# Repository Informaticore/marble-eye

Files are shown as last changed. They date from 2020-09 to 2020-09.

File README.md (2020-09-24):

# Marble Eye
Marble Eye is an IR pass through Sensor for a project I am working on. It can detect objects which are passing by at a distance with up to 2cm.

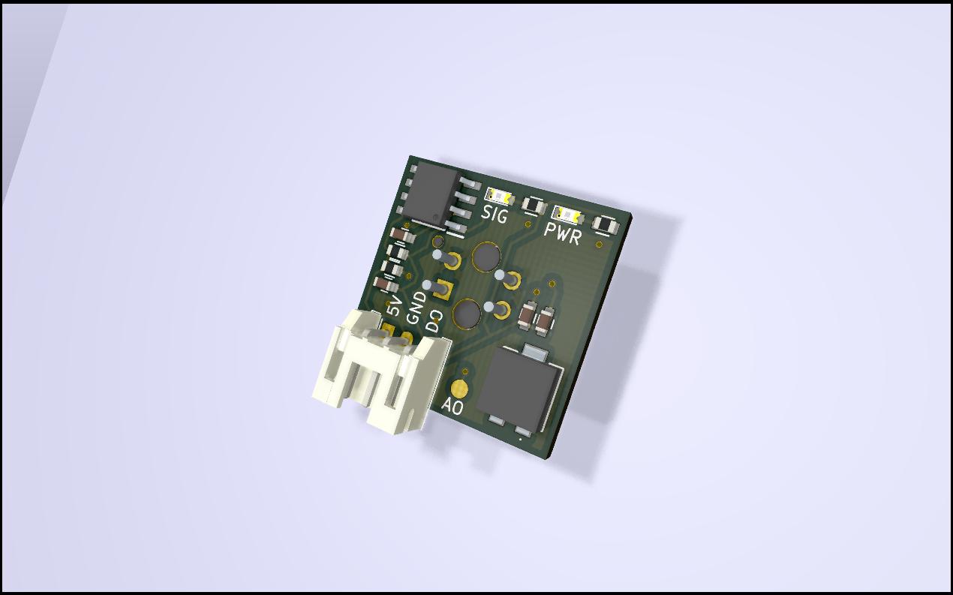
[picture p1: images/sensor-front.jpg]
Marble Eye Front

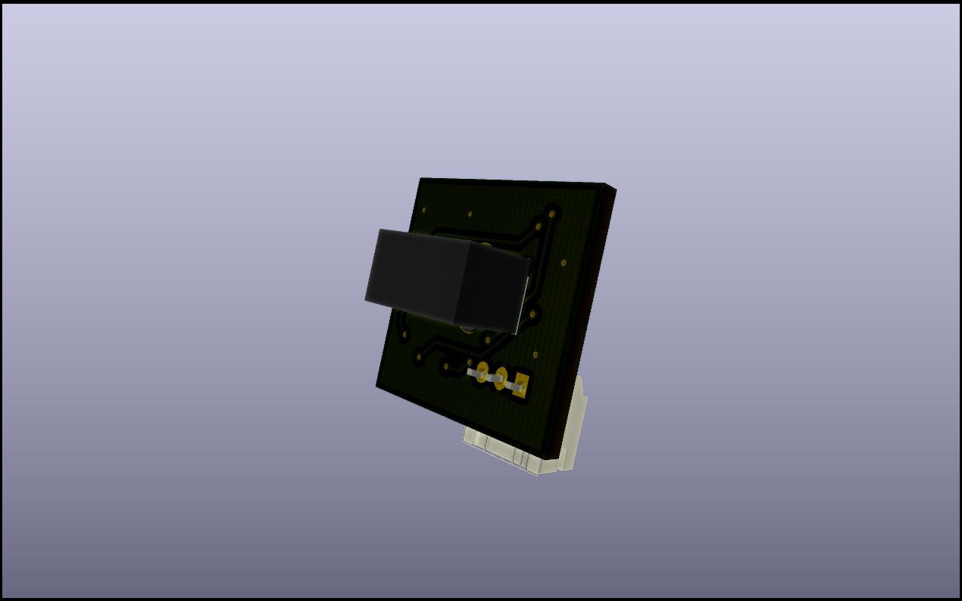
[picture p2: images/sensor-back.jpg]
Marble Eye Back


# Marble Eye Hub
The Marble Eye Hub is a GPIO-Expander with 16 Ports to connect up to 16 Marble Eyes to it. Based on interrupts the Hub can detect pass through on all 16 channels.

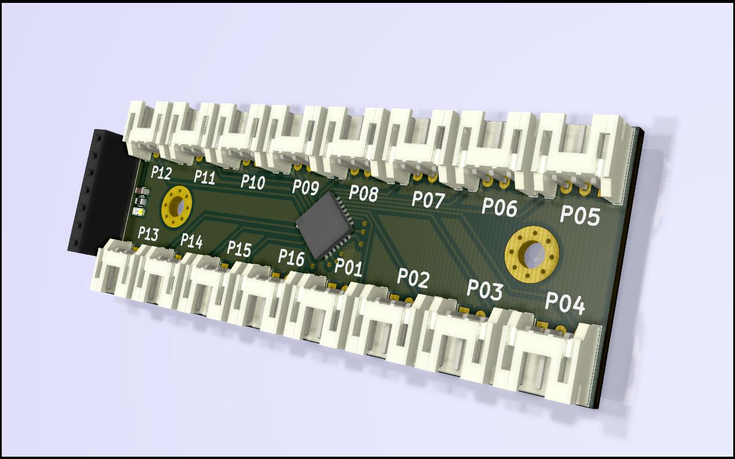
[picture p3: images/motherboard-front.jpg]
Marble Eye Hub


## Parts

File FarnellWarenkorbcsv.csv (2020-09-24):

Nr. | Best.-Nr. | RoHS-konform? | Ihre Bestellnummer | Hinweise | Menge | Hersteller-Teilenr. | Herstellername | Hersteller / Beschreibung | Verfügbarkeit | Stückpreis | Positionspreis | Rabattpreis
1 | 2059601 | RoHS: Y-EX / PHTHALATE: YES |  |  | 10.0 | ERJ3GEYJ102V | PANASONIC | PANASONIC Chipwiderstand, Oberflächenmontage, Dickschicht, 0603 [Metrisch 1608], 1 kohm, Baureihe ERJ3G, 75 V | 151696 | 0.0579 | 0.58
2 | 2059583 | RoHS: Y-EX / PHTHALATE: YES |  |  | 10.0 | ERJ3GEYJ221V | PANASONIC | PANASONIC Chipwiderstand, Oberflächenmontage, Dickschicht, 0603 [Metrisch 1608], 220 ohm, Baureihe ERJ3G | 11262 | 0.0565 | 0.57
3 | 2059627 | RoHS: Y-EX / PHTHALATE: YES |  |  | 20.0 | ERJ3GEYJ103V | PANASONIC | PANASONIC Chipwiderstand, Oberflächenmontage, Dickschicht, 0603 [Metrisch 1608], 10 kohm, Baureihe ERJ3G | 343293 | 0.0551 | 1.10
4 | 3616198 | RoHS: YES / PHTHALATE: YES |  |  | 100.0 | PHR-3 | JST (JAPAN SOLDERLESS TERMINALS) | JST (JAPAN SOLDERLESS TERMINALS) Steckverbindergehäuse, Baureihe PH, Buchse, 3 -polig, 2 mm, Crimpkontakte der Baureihen BPH und SPH | 113015 | 0.0389 | 3.89
5 | 9491910 | RoHS: YES / PHTHALATE: YES |  |  | 100.0 | S3B-PH-K-S (LF)(SN) | JST (JAPAN SOLDERLESS TERMINALS) | JST (JAPAN SOLDERLESS TERMINALS) Stiftleiste, abgewinkelt, Wire-to-Board, 2 mm, 1 Reihe(n), 3 Kontakt(e) | 3933 | 0.0940 | 9.40
6 | 1671245 | RoHS: YES / PHTHALATE: YES |  |  | 300.0 | SPH-002T-P0.5S | JST (JAPAN SOLDERLESS TERMINALS) | JST (JAPAN SOLDERLESS TERMINALS) Kontakt, Baureihe PH, Buchsenkontakt, Crimpanschluss, 24 AWG, Verzinnte Kontakte | 155877 | 0.0244 | 7.32
7 | 2322071 | RoHS: YES / PHTHALATE: YES |  |  | 50.0 | 150060RS75000 | WURTH ELEKTRONIK | WURTH ELEKTRONIK LED, Rot, Oberflächenmontage, 603, 30 mA, 2 V, 625 nm | 7565 | 0.1430 | 7.15
8 | 2303104 | RoHS: Y-EX / PHTHALATE: YES |  |  | 100.0 | ERJ3EKF3300V | PANASONIC | PANASONIC Chipwiderstand, Oberflächenmontage, Dickschicht, 0603 [Metrisch 1608], 330 ohm, Baureihe ERJ3E | 15098 | 0.0365 | 3.65
9 | 2210887 | RoHS: YES / PHTHALATE: YES |  |  | 100.0 | CGA3E2X8R1E104K080AA | TDK | TDK Keramikvielschichtkondensator, SMD, 0.1 µF, 25 V, 0603 [Metrisch 1608], ± 10%, X8R, Baureihe CGA | 78194 | 0.0715 | 7.15
10 | 1470066 | RoHS: YES / PHTHALATE: YES |  |  | 10.0 | TCRT5000 | VISHAY | VISHAY Reflexlichtschranke, Fototransistor, Durchsteckmontage, 15mm, 60mA, 5Vr, 1.25Vf | 1556 | 1.0700 | 10.70
11 | 1141474 | RoHS: YES / PHTHALATE: YES |  |  | 10.0 | TS53YL103MR10 | VISHAY | VISHAY Trimmpotentiometer, Eingängig, Cermet, Einstellung oben, 10 kohm, Oberflächenmontage | 5750 | 1.0600 | 10.60
12 | 2857786 | RoHS: YES / PHTHALATE: YES |  |  | 5.0 | MCP23017T-E/ML | MICROCHIP | MICROCHIP I/O-Erweiterung, 16bit, 1.7 MHz, I2C, 1.8 V, 5.5 V, QFN | 3178 | 1.3400 | 6.70
 |  |  |  |  |  |  | Zwischensumme | 68.81
 |  |  |  |  |  |  | Warengesamtsumme | 68.81
 |  |  |  |  |  |  | Lieferung | 0.00
 |  |  |  |  |  |  | USt. | 13.07
 |  |  |  |  |  |  | Gesamt | 81.88

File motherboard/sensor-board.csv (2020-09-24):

Source: | C:\Users\Informatic0re\Documents\workspace\ir-detector\motherboard\sensor-board.sch
Date: | 07/06/2020 14:44:52
Tool: | Eeschema (5.1.2)-1
Generator: | E:\KiCad\bin\scripting\plugins/bom_csv_grouped_by_value.py
Component Count: | 23
Individual Components:
Item | Qty | Reference(s) | Value | LibPart | Footprint | Datasheet | Link | ManufacturerId
 |  | C1 | 100nF | Device:C | Capacitors_SMD:C_0603 | ~ | https://www.mouser.de/ProductDetail/81-GCJ188R71C104MA1D | GCJ188R71C104MA01D
 |  | D1 | LED | Device:LED | LEDs:LED_0603 | ~ | https://www.mouser.de/ProductDetail/710-150060RS75000 | 150060RS75000
 |  | H1 | MountingHole | Mechanical:MountingHole | Mounting_Holes:MountingHole_3mm_Pad_Via | ~
 |  | H2 | MountingHole | Mechanical:MountingHole | Mounting_Holes:MountingHole_3mm_Pad_Via | ~
 |  | J1 | S3B-PH | Connector:Conn_01x03_Male | Connectors_JST:JST_PH_S3B-PH-K_03x2.00mm_Angled | ~ | https://de.farnell.com/jst-japan-solderless-terminals/s3b-ph-k-s-lf-sn/stecker-seitlicher-eing-3kont/dp/9491910 | S3B-PH-K-S (LF)(SN)
 |  | J2 | S3B-PH | Connector:Conn_01x03_Male | Connectors_JST:JST_PH_S3B-PH-K_03x2.00mm_Angled | ~ | https://de.farnell.com/jst-japan-solderless-terminals/s3b-ph-k-s-lf-sn/stecker-seitlicher-eing-3kont/dp/9491910 | S3B-PH-K-S (LF)(SN)
 |  | J3 | S3B-PH | Connector:Conn_01x03_Male | Connectors_JST:JST_PH_S3B-PH-K_03x2.00mm_Angled | ~ | https://de.farnell.com/jst-japan-solderless-terminals/s3b-ph-k-s-lf-sn/stecker-seitlicher-eing-3kont/dp/9491910 | S3B-PH-K-S (LF)(SN)
 |  | J4 | S3B-PH | Connector:Conn_01x03_Male | Connectors_JST:JST_PH_S3B-PH-K_03x2.00mm_Angled | ~ | https://de.farnell.com/jst-japan-solderless-terminals/s3b-ph-k-s-lf-sn/stecker-seitlicher-eing-3kont/dp/9491910 | S3B-PH-K-S (LF)(SN)
 |  | J5 | S3B-PH | Connector:Conn_01x03_Male | Connectors_JST:JST_PH_S3B-PH-K_03x2.00mm_Angled | ~ | https://de.farnell.com/jst-japan-solderless-terminals/s3b-ph-k-s-lf-sn/stecker-seitlicher-eing-3kont/dp/9491910 | S3B-PH-K-S (LF)(SN)
 |  | J6 | S3B-PH | Connector:Conn_01x03_Male | Connectors_JST:JST_PH_S3B-PH-K_03x2.00mm_Angled | ~ | https://de.farnell.com/jst-japan-solderless-terminals/s3b-ph-k-s-lf-sn/stecker-seitlicher-eing-3kont/dp/9491910 | S3B-PH-K-S (LF)(SN)
 |  | J7 | S3B-PH | Connector:Conn_01x03_Male | Connectors_JST:JST_PH_S3B-PH-K_03x2.00mm_Angled | ~ | https://de.farnell.com/jst-japan-solderless-terminals/s3b-ph-k-s-lf-sn/stecker-seitlicher-eing-3kont/dp/9491910 | S3B-PH-K-S (LF)(SN)
 |  | J8 | S3B-PH | Connector:Conn_01x03_Male | Connectors_JST:JST_PH_S3B-PH-K_03x2.00mm_Angled | ~ | https://de.farnell.com/jst-japan-solderless-terminals/s3b-ph-k-s-lf-sn/stecker-seitlicher-eing-3kont/dp/9491910 | S3B-PH-K-S (LF)(SN)
 |  | J9 | S3B-PH | Connector:Conn_01x03_Male | Connectors_JST:JST_PH_S3B-PH-K_03x2.00mm_Angled | ~ | https://de.farnell.com/jst-japan-solderless-terminals/s3b-ph-k-s-lf-sn/stecker-seitlicher-eing-3kont/dp/9491910 | S3B-PH-K-S (LF)(SN)
 |  | J10 | S3B-PH | Connector:Conn_01x03_Male | Connectors_JST:JST_PH_S3B-PH-K_03x2.00mm_Angled | ~ | https://de.farnell.com/jst-japan-solderless-terminals/s3b-ph-k-s-lf-sn/stecker-seitlicher-eing-3kont/dp/9491910 | S3B-PH-K-S (LF)(SN)
 |  | J11 | S3B-PH | Connector:Conn_01x03_Male | Connectors_JST:JST_PH_S3B-PH-K_03x2.00mm_Angled | ~ | https://de.farnell.com/jst-japan-solderless-terminals/s3b-ph-k-s-lf-sn/stecker-seitlicher-eing-3kont/dp/9491910 | S3B-PH-K-S (LF)(SN)
 |  | J12 | S3B-PH | Connector:Conn_01x03_Male | Connectors_JST:JST_PH_S3B-PH-K_03x2.00mm_Angled | ~ | https://de.farnell.com/jst-japan-solderless-terminals/s3b-ph-k-s-lf-sn/stecker-seitlicher-eing-3kont/dp/9491910 | S3B-PH-K-S (LF)(SN)
 |  | J13 | S3B-PH | Connector:Conn_01x03_Male | Connectors_JST:JST_PH_S3B-PH-K_03x2.00mm_Angled | ~ | https://de.farnell.com/jst-japan-solderless-terminals/s3b-ph-k-s-lf-sn/stecker-seitlicher-eing-3kont/dp/9491910 | S3B-PH-K-S (LF)(SN)
 |  | J14 | S3B-PH | Connector:Conn_01x03_Male | Connectors_JST:JST_PH_S3B-PH-K_03x2.00mm_Angled | ~ | https://de.farnell.com/jst-japan-solderless-terminals/s3b-ph-k-s-lf-sn/stecker-seitlicher-eing-3kont/dp/9491910 | S3B-PH-K-S (LF)(SN)
 |  | J15 | S3B-PH | Connector:Conn_01x03_Male | Connectors_JST:JST_PH_S3B-PH-K_03x2.00mm_Angled | ~ | https://de.farnell.com/jst-japan-solderless-terminals/s3b-ph-k-s-lf-sn/stecker-seitlicher-eing-3kont/dp/9491910 | S3B-PH-K-S (LF)(SN)
 |  | J16 | S3B-PH | Connector:Conn_01x03_Male | Connectors_JST:JST_PH_S3B-PH-K_03x2.00mm_Angled | ~ | https://de.farnell.com/jst-japan-solderless-terminals/s3b-ph-k-s-lf-sn/stecker-seitlicher-eing-3kont/dp/9491910 | S3B-PH-K-S (LF)(SN)
 |  | J17 | DNP | Connector:Conn_01x06_Male | Connector_PinSocket_2.54mm:PinSocket_1x06_P2.54mm_Vertical | ~
 |  | R1 | 300 | Device:R | Resistors_SMD:R_0603 | ~ | https://www.mouser.de/ProductDetail/667-ERJ-3RBD3000V | ERJ-3RBD3000V
 |  | U1 | MCP23017_ML | Interface_Expansion:MCP23017_ML | motherboard:QFN65P600X600X100-29N-D | http://ww1.microchip.com/downloads/en/DeviceDoc/20001952C.pdf |  | 74438366015
Collated Components:
Item | Qty | Reference(s) | Value | LibPart | Footprint | Datasheet | Link | ManufacturerId
1 | 1 | C1 | 100nF | Device:C | Capacitors_SMD:C_0603 | ~ | https://www.mouser.de/ProductDetail/81-GCJ188R71C104MA1D | GCJ188R71C104MA01D
2 | 1 | D1 | LED | Device:LED | LEDs:LED_0603 | ~ | https://www.mouser.de/ProductDetail/710-150060RS75000 | 150060RS75000
3 | 2 | H1, H2 | MountingHole | Mechanical:MountingHole | Mounting_Holes:MountingHole_3mm_Pad_Via | ~
4 | 16 | J1, J2, J3, J4, J5, J6, J7, J8, J9, J10, J11, J12, J13, J14, J15, J16 | S3B-PH | Connector:Conn_01x03_Male | Connectors_JST:JST_PH_S3B-PH-K_03x2.00mm_Angled | ~ | https://de.farnell.com/jst-japan-solderless-terminals/s3b-ph-k-s-lf-sn/stecker-seitlicher-eing-3kont/dp/9491910 | S3B-PH-K-S (LF)(SN)
5 | 1 | J17 | DNP | Connector:Conn_01x06_Male | Connector_PinSocket_2.54mm:PinSocket_1x06_P2.54mm_Vertical | ~
6 | 1 | R1 | 300 | Device:R | Resistors_SMD:R_0603 | ~ | https://www.mouser.de/ProductDetail/667-ERJ-3RBD3000V | ERJ-3RBD3000V
7 | 1 | U1 | MCP23017_ML | Interface_Expansion:MCP23017_ML | motherboard:QFN65P600X600X100-29N-D | http://ww1.microchip.com/downloads/en/DeviceDoc/20001952C.pdf |  | 74438366015

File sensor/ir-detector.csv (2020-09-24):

Source: | C:\Users\Informatic0re\Documents\workspace\ir-detector\sensor\ir-detector.sch
Date: | 07/06/2020 14:44:30
Tool: | Eeschema (5.1.2)-1
Generator: | E:\KiCad\bin\scripting\plugins/bom_csv_grouped_by_value.py
Component Count: | 15
Individual Components:
Item | Qty | Reference(s) | Value | LibPart | Footprint | Datasheet | Allied Price/Stock | Allied_Number | Arrow Part Number | Arrow Price/Stock | Description | Height | Manufacturer_Name | Manufacturer_Part_Number | Mouser Part Number | Mouser Price/Stock | RS Part Number | RS Price/Stock
 |  | C1 | 104 | Device:C | Capacitors_SMD:C_0603 | ~
 |  | C2 | 104 | Device:C | Capacitors_SMD:C_0603 | ~
 |  | D1 | LED | Device:LED | LEDs:LED_0603 | ~
 |  | D2 | LED | Device:LED | LEDs:LED_0603 | ~
 |  | H1 | M2 | Mechanical:MountingHole | Mounting_Holes:MountingHole_2.2mm_M2_Pad_Via | ~
 |  | IC1 | LM393DR | LM393DR:LM393DR | ir-detector:SOIC127P600X175-8N | http://docs-emea.rs-online.com/webdocs/14b2/0900766b814b2f20.pdf |  |  | LM393DR | https://www.arrow.com/en/products/lm393dr/texas-instruments | LM393DR, Dual Comparator Open Collector 1.3us 12 V, 15 V, 18 V, 24 V, 28 V, 3 V, 5 V, 9 V 8-Pin SOIC | 1.75 | Texas Instruments | LM393DR | 595-LM393DR | https://www.mouser.co.uk/ProductDetail/Texas-Instruments/LM393DR?qs=8k%2FZSzWMuCP%2FrtMSX0i7pQ%3D%3D
 |  | J1 | Conn_01x03_Male | Connector:Conn_01x03_Male | Connectors_JST:JST_PH_S3B-PH-K_03x2.00mm_Angled | ~
 |  | Q1 | TCRT5000 | TCRT5000:TCRT5000 | ir-detector:TCRT5000 | http://www.vishay.com/docs/83760/tcrt5000.pdf | http://www.alliedelec.com/vishay-dale-tcrt5000/R1084611/ | R1084611 |  |  | VISHAY - TCRT5000. - SENSOR, OPTICAL, TRANSISTOR O/P | 6.8 | Vishay | TCRT5000 | 782-TCRT5000 | https://www.mouser.co.uk/ProductDetail/Vishay-Semiconductors/TCRT5000?qs=glpcD2KT6uaaYldHGIIt5g%3D%3D | 7085017P | http://uk.rs-online.com/web/p/products/7085017P
 |  | R1 | 220 | Device:R | Resistors_SMD:R_0603 | ~
 |  | R2 | 10k | Device:R | Resistors_SMD:R_0603 | ~
 |  | R3 | 1k | Device:R | Resistors_SMD:R_0603 | ~
 |  | R4 | 10k | Device:R | Resistors_SMD:R_0603 | ~
 |  | R5 | 330 | Device:R | Resistors_SMD:R_0603 | ~
 |  | R6 | 330 | Device:R | Resistors_SMD:R_0603 | ~
 |  | VR1 | TS53YL_10K_20%TR | TS53YL_10K:TS53YL_10K_20%TR | ir-detector:TS53YL204MR10 | https://www.vishay.com/doc?51008 |  |  | TS53YL 10K 20%TR |  | Trimmer Resistors - SMD TS53YL103MR10 | 2 | Vishay | TS53YL 10K 20%TR | 75-TS53YL10K20%TR | https://www.mouser.co.uk/ProductDetail/Vishay-Sprague/TS53YL-10K-20TR?qs=fbr3QJcAB6rQumgcAWaZQw%3D%3D
Collated Components:
Item | Qty | Reference(s) | Value | LibPart | Footprint | Datasheet | Allied Price/Stock | Allied_Number | Arrow Part Number | Arrow Price/Stock | Description | Height | Manufacturer_Name | Manufacturer_Part_Number | Mouser Part Number | Mouser Price/Stock | RS Part Number | RS Price/Stock
1 | 2 | C1, C2 | 104 | Device:C | Capacitors_SMD:C_0603 | ~
2 | 2 | D1, D2 | LED | Device:LED | LEDs:LED_0603 | ~
3 | 1 | H1 | M2 | Mechanical:MountingHole | Mounting_Holes:MountingHole_2.2mm_M2_Pad_Via | ~
4 | 1 | IC1 | LM393DR | LM393DR:LM393DR | ir-detector:SOIC127P600X175-8N | http://docs-emea.rs-online.com/webdocs/14b2/0900766b814b2f20.pdf |  |  | LM393DR | https://www.arrow.com/en/products/lm393dr/texas-instruments | LM393DR, Dual Comparator Open Collector 1.3us 12 V, 15 V, 18 V, 24 V, 28 V, 3 V, 5 V, 9 V 8-Pin SOIC | 1.75 | Texas Instruments | LM393DR | 595-LM393DR | https://www.mouser.co.uk/ProductDetail/Texas-Instruments/LM393DR?qs=8k%2FZSzWMuCP%2FrtMSX0i7pQ%3D%3D
5 | 1 | J1 | Conn_01x03_Male | Connector:Conn_01x03_Male | Connectors_JST:JST_PH_S3B-PH-K_03x2.00mm_Angled | ~
6 | 1 | Q1 | TCRT5000 | TCRT5000:TCRT5000 | ir-detector:TCRT5000 | http://www.vishay.com/docs/83760/tcrt5000.pdf | http://www.alliedelec.com/vishay-dale-tcrt5000/R1084611/ | R1084611 |  |  | VISHAY - TCRT5000. - SENSOR, OPTICAL, TRANSISTOR O/P | 6.8 | Vishay | TCRT5000 | 782-TCRT5000 | https://www.mouser.co.uk/ProductDetail/Vishay-Semiconductors/TCRT5000?qs=glpcD2KT6uaaYldHGIIt5g%3D%3D | 7085017P | http://uk.rs-online.com/web/p/products/7085017P
7 | 1 | R1 | 220 | Device:R | Resistors_SMD:R_0603 | ~
8 | 2 | R2, R4 | 10k | Device:R | Resistors_SMD:R_0603 | ~
9 | 1 | R3 | 1k | Device:R | Resistors_SMD:R_0603 | ~
10 | 2 | R5, R6 | 330 | Device:R | Resistors_SMD:R_0603 | ~
11 | 1 | VR1 | TS53YL_10K_20%TR | TS53YL_10K:TS53YL_10K_20%TR | ir-detector:TS53YL204MR10 | https://www.vishay.com/doc?51008 |  |  | TS53YL 10K 20%TR |  | Trimmer Resistors - SMD TS53YL103MR10 | 2 | Vishay | TS53YL 10K 20%TR | 75-TS53YL10K20%TR | https://www.mouser.co.uk/ProductDetail/Vishay-Sprague/TS53YL-10K-20TR?qs=fbr3QJcAB6rQumgcAWaZQw%3D%3D

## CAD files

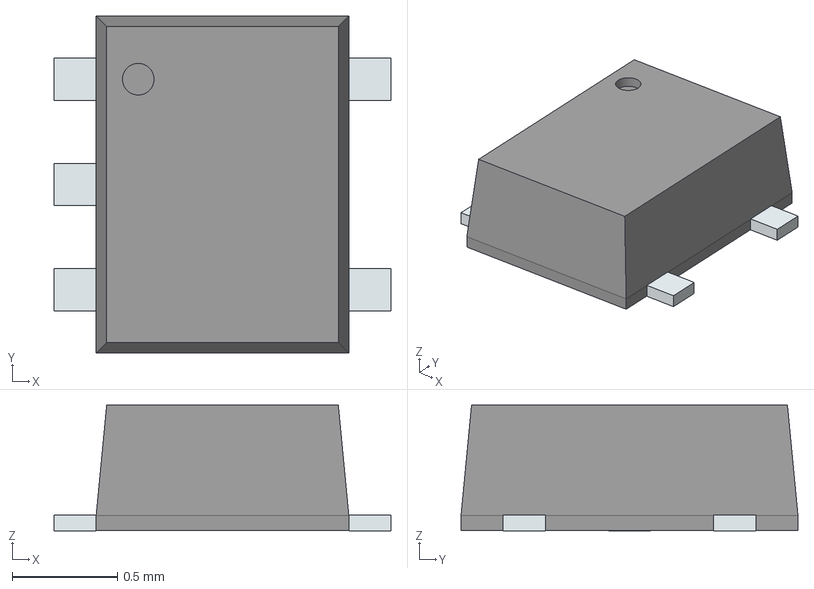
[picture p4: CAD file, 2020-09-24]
motherboard/components/SN74LVC1G32DRLR/3D/SN74LVC1G32DRLR.stp
1.60 x 1.60 x 0.598 mm
PinsArrayL
PinsArrayR

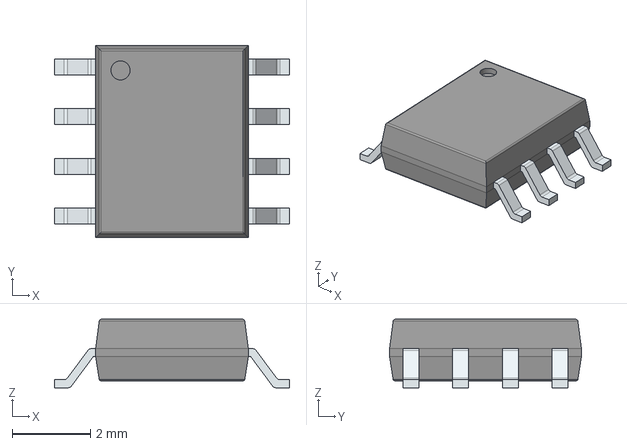
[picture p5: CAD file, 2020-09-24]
sensor/components/LM393DR/3D/LM393DR.stp
6.00 x 4.90 x 1.75 mm
PinsArrayLR

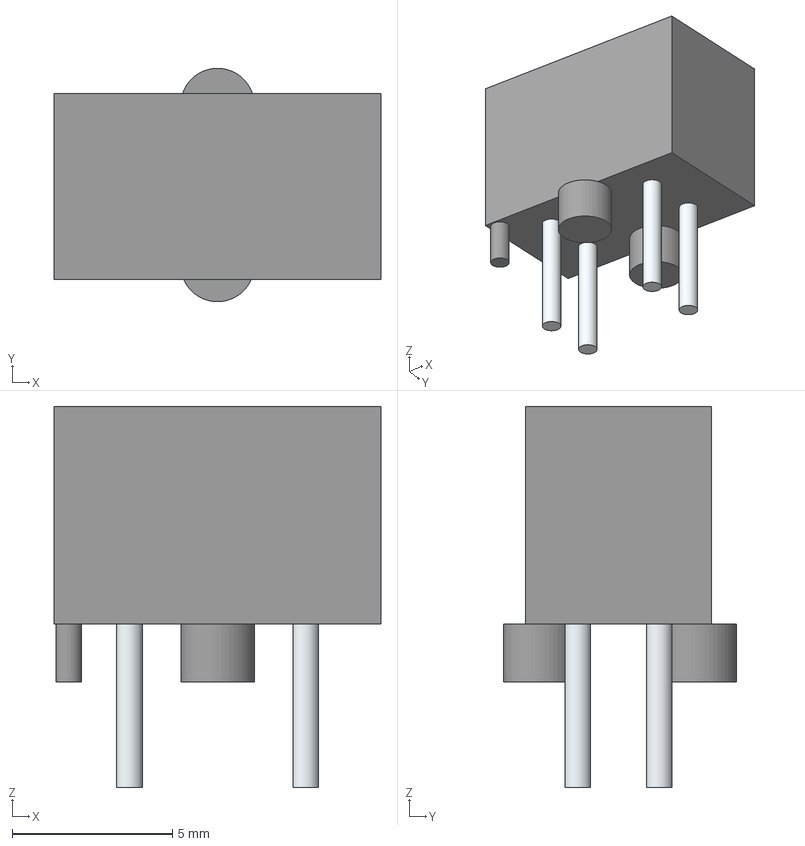
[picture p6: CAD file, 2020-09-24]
sensor/components/TCRT5000/3D/TCRT5000.stp
10.2 x 7.29 x 11.9 mm
Lugs x 7
Leads x 7

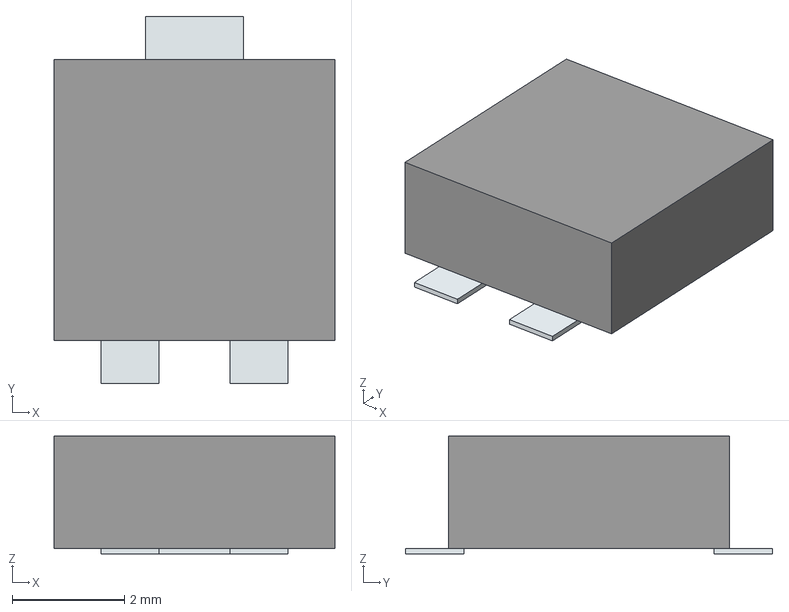
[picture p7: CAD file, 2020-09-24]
sensor/components/TS53YL_10K/3D/TS53YL_10K.stp
5.00 x 6.54 x 2.10 mm
Pins

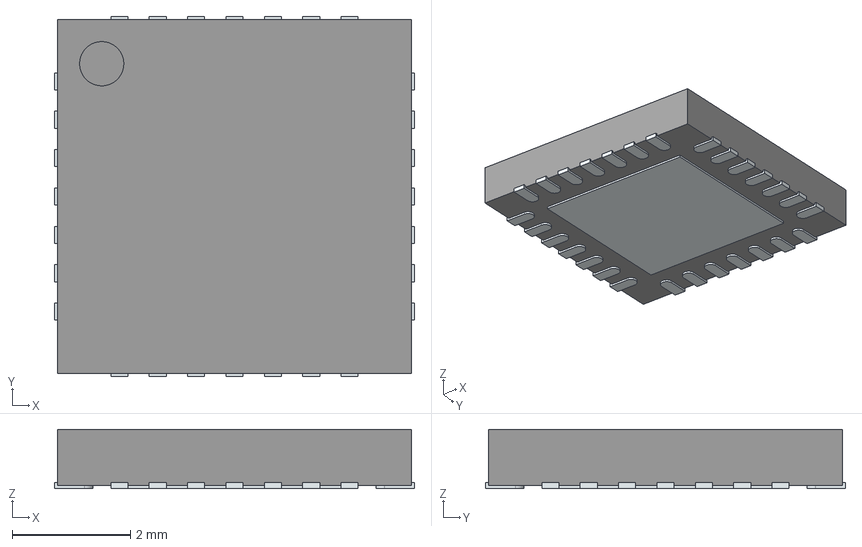
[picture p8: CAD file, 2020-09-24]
motherboard/components/MCP23017T-E_ML/3D/MCP23017T-E_ML.stp
6.10 x 6.10 x 1.00 mm
ThermalPin
PinsArrayLR
PinsArrayTB

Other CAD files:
motherboard/components/MCP23017T-E_ML/3D/MCP23017T-E_ML.stl
motherboard/components/SN74LVC1G32DRLR/3D/SN74LVC1G32DRLR.stl
sensor/components/LM393DR/3D/LM393DR.stl
sensor/components/TCRT5000/3D/TCRT5000.stl
sensor/components/TS53YL_10K/3D/TS53YL_10K.stl

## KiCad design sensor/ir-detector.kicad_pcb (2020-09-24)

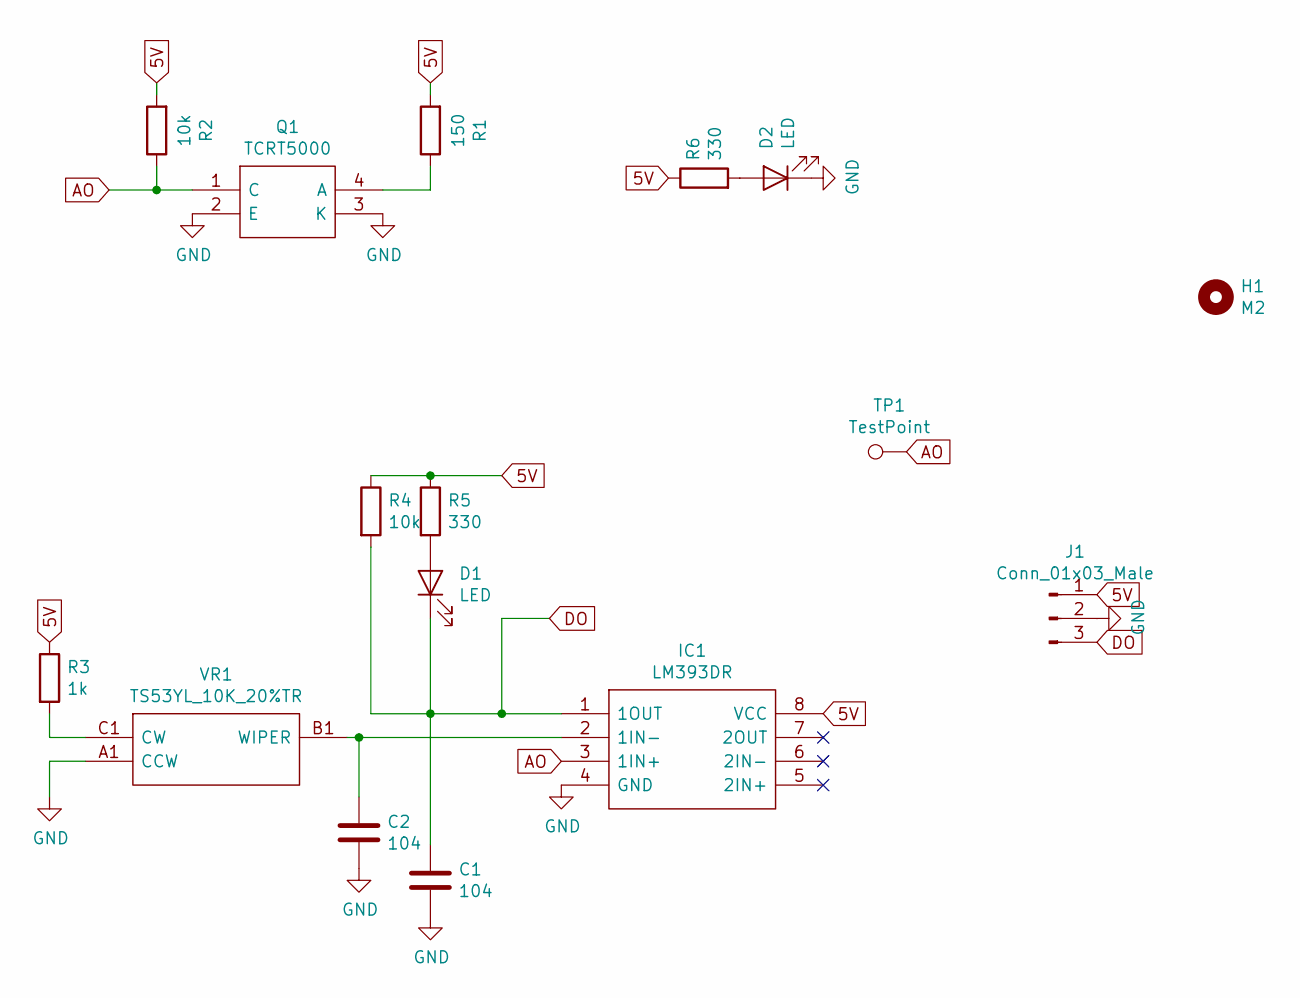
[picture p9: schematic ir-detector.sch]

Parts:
C1, C2: 104; C_0603
D1, D2: LED; LED_0603
H1: M2; MountingHole_2.2mm_M2_Pad_Via
IC1: LM393DR; SOIC127P600X175-8N; Manufacturer_Part_Number LM393DR; Mouser Part Number 595-LM393DR
J1: Conn_01x03_Male; JST_PH_S3B-PH-K_03x2.00mm_Angled
Q1: TCRT5000; Manufacturer_Part_Number TCRT5000; Mouser Part Number 782-TCRT5000
R1: 150; R_0603
R2, R4: 10k; R_0603
R3: 1k; R_0603
R5, R6: 330; R_0603
TP1: TestPoint; Measurement_Point_Round-SMD-Pad_Small
VR1: TS53YL_10K_20%TR; TS53YL204MR10; Manufacturer_Part_Number TS53YL 10K 20%TR; Mouser Part Number 75-TS53YL10K20%TR

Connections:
5V: IC1.8 (VCC), J1.1, R1.2, R2.2, R3.1, R4.1, R5.1, R6.1
AO: IC1.3 (1IN+), Q1.1 (C), R2.1, TP1.1
DO: C1.1, D1.1 (K), IC1.1 (1OUT), J1.3, R4.2
GND: C1.2, C2.2, D2.1 (K), IC1.4 (GND), J1.2, Q1.2 (E), Q1.3 (K), VR1.A1 (CCW)
unnamed: C2.1, IC1.2 (1IN-), VR1.B1 (WIPER)
unnamed: D1.2 (A), R5.2
unnamed: D2.2 (A), R6.2
unnamed: Q1.4 (A), R1.1
unnamed: R3.2, VR1.C1 (CW)

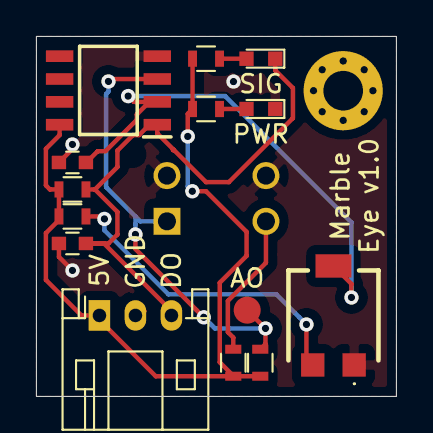
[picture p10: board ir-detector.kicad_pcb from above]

Board: 2 copper layers, 20.0 x 20.0 mm, 16 parts (1 on the bottom side), 9 nets.

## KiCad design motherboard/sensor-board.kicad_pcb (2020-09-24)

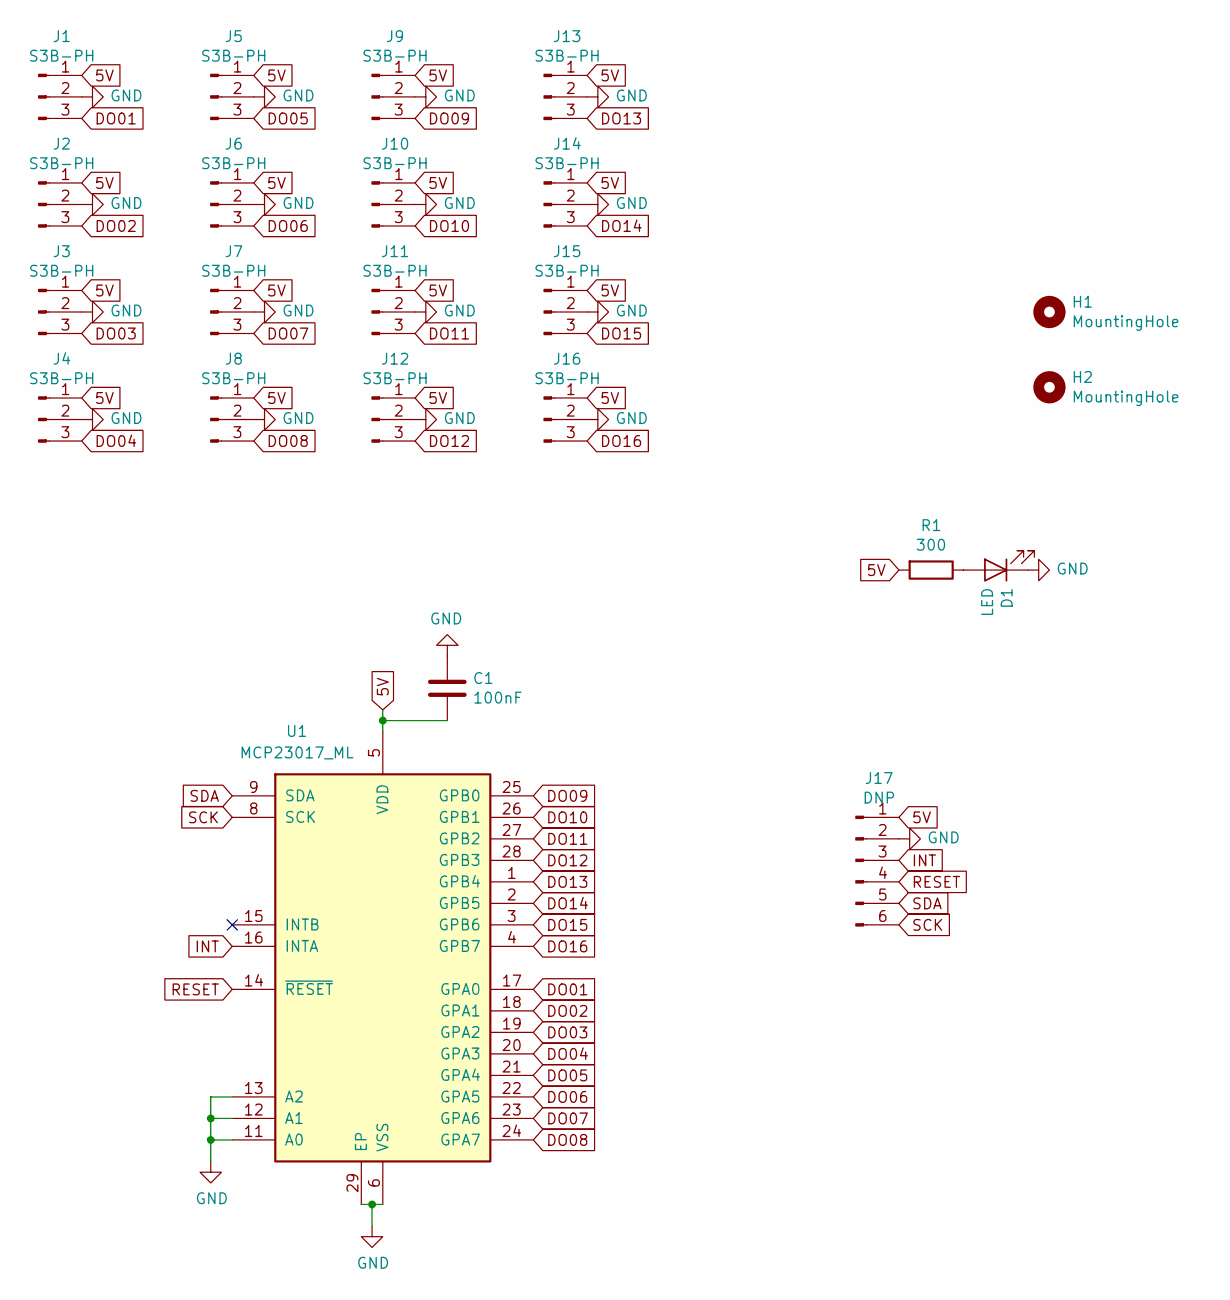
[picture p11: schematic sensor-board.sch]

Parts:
C1: 100nF; C_0603
D1: LED; LED_0603
H1, H2: MountingHole; MountingHole_3mm_Pad_Via
J1, J2, J3, J4, J5, J6, J7, J8, J9, J10, J11, J12, J13, J14, J15, J16: S3B-PH; JST_PH_S3B-PH-K_03x2.00mm_Angled
J17: DNP; PinSocket_1x06_P2.54mm_Vertical
R1: 300; R_0603
U1: MCP23017_ML; QFN65P600X600X100-29N-D

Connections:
5V: C1.2, J1.1, J2.1, J3.1, J4.1, J5.1, J6.1, J7.1, J8.1, J9.1, J10.1, J11.1, J12.1, J13.1, J14.1, J15.1, J16.1, J17.1, R1.2, U1.5 (VDD)
DO01: J1.3, U1.17 (GPA0)
DO02: J2.3, U1.18 (GPA1)
DO03: J3.3, U1.19 (GPA2)
DO04: J4.3, U1.20 (GPA3)
DO05: J5.3, U1.21 (GPA4)
DO06: J6.3, U1.22 (GPA5)
DO07: J7.3, U1.23 (GPA6)
DO08: J8.3, U1.24 (GPA7)
DO09: J9.3, U1.25 (GPB0)
DO10: J10.3, U1.26 (GPB1)
DO11: J11.3, U1.27 (GPB2)
DO12: J12.3, U1.28 (GPB3)
DO13: J13.3, U1.1 (GPB4)
DO14: J14.3, U1.2 (GPB5)
DO15: J15.3, U1.3 (GPB6)
DO16: J16.3, U1.4 (GPB7)
GND: C1.1, D1.1 (K), J1.2, J2.2, J3.2, J4.2, J5.2, J6.2, J7.2, J8.2, J9.2, J10.2, J11.2, J12.2, J13.2, J14.2, J15.2, J16.2, J17.2, U1.6 (VSS), U1.11 (A0), U1.12 (A1), U1.13 (A2), U1.29 (EP)
INT: J17.3, U1.16 (INTA)
unnamed: D1.2 (A), R1.1
RESET: J17.4, U1.14 (~RESET~)
SCK: J17.6, U1.8 (SCK)
SDA: J17.5, U1.9 (SDA)

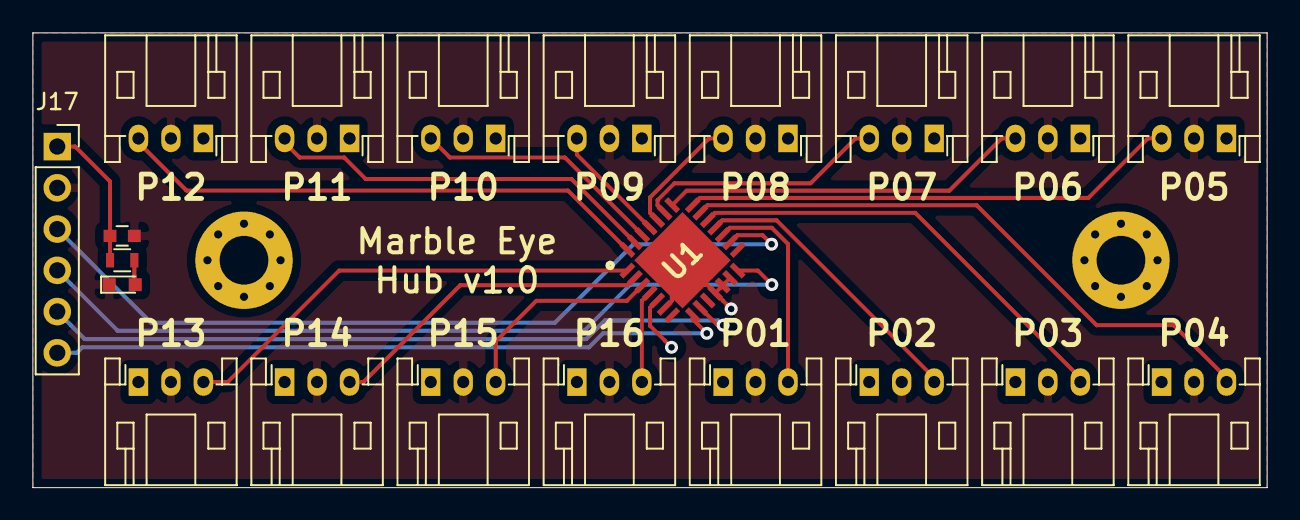
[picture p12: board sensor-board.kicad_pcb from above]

Board: 2 copper layers, 76.0 x 28.0 mm, 23 parts (0 on the bottom side), 23 nets.
